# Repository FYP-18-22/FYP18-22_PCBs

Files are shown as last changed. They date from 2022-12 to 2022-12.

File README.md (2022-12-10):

This repository holds all our electrical and electronics designs.

Contains files for a main PCB and an actuation PCB.

The main PCB uses an STM32F103CC controller and provides for interfacing with various sensors. It also interacts with our actuation PCB by accepting the zero-crossing detection signal from the actuation PCB and sends back actuation commands to it.

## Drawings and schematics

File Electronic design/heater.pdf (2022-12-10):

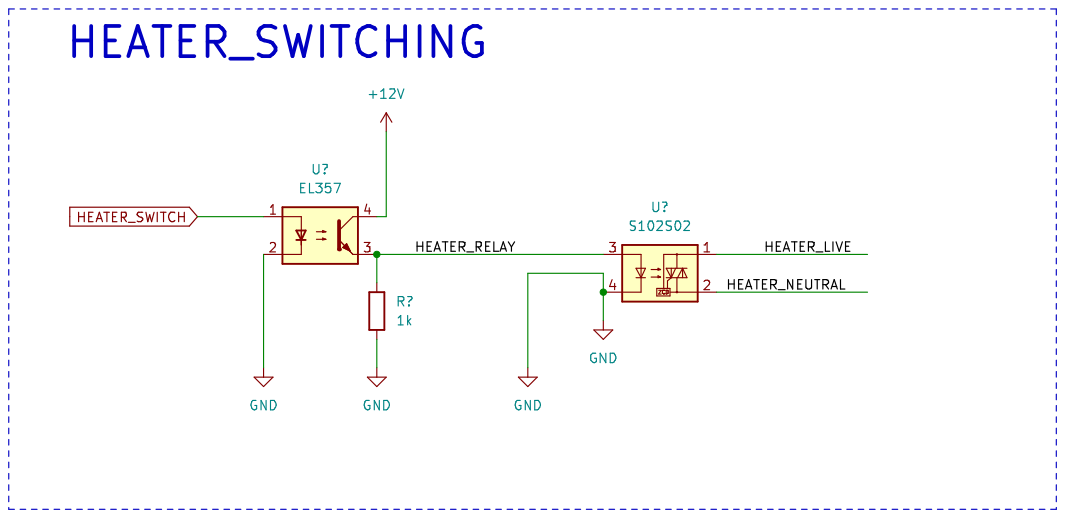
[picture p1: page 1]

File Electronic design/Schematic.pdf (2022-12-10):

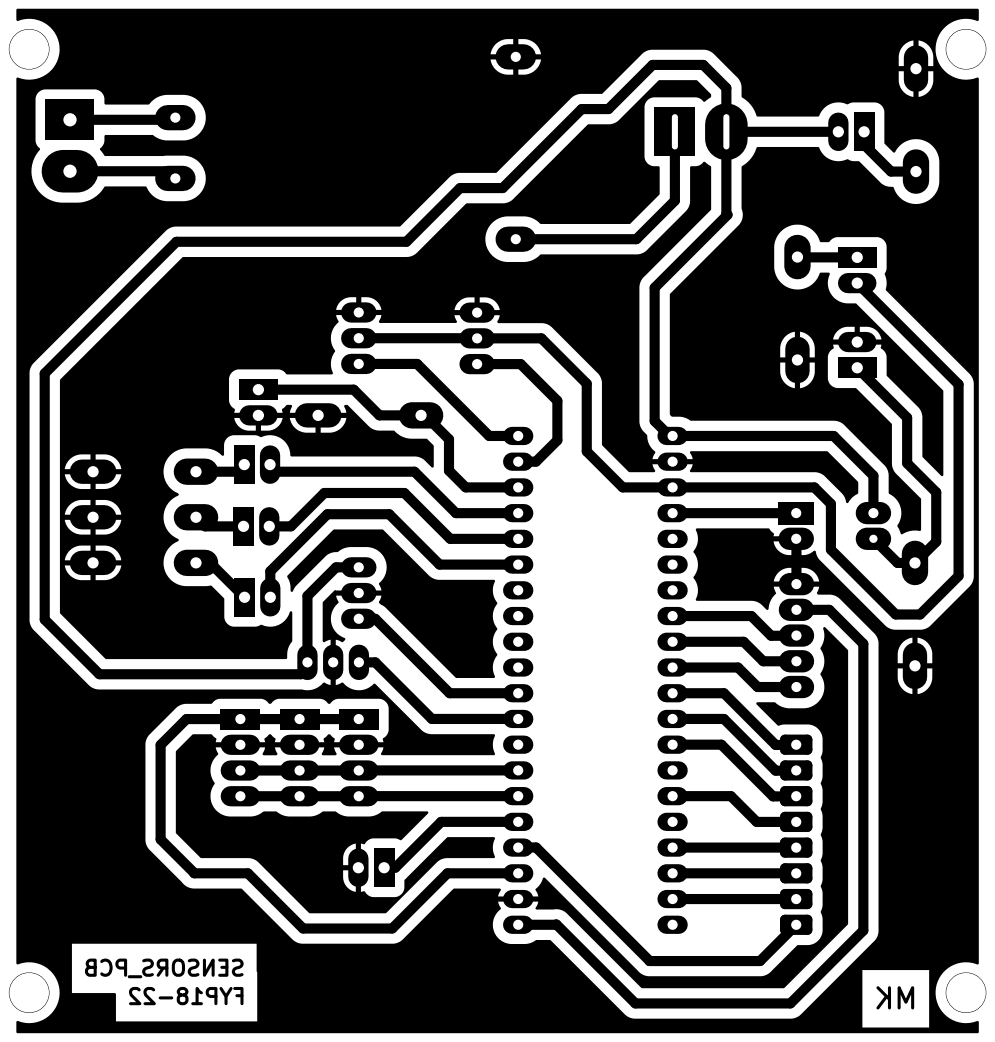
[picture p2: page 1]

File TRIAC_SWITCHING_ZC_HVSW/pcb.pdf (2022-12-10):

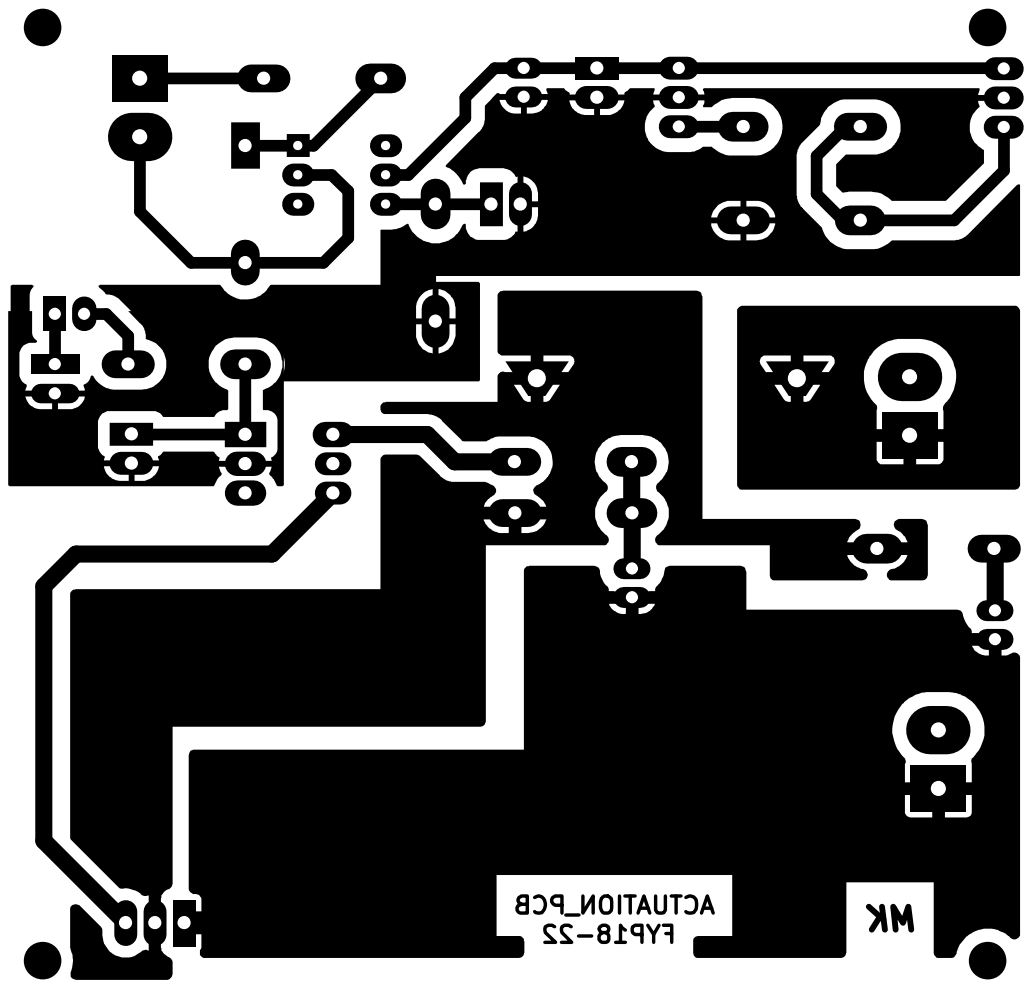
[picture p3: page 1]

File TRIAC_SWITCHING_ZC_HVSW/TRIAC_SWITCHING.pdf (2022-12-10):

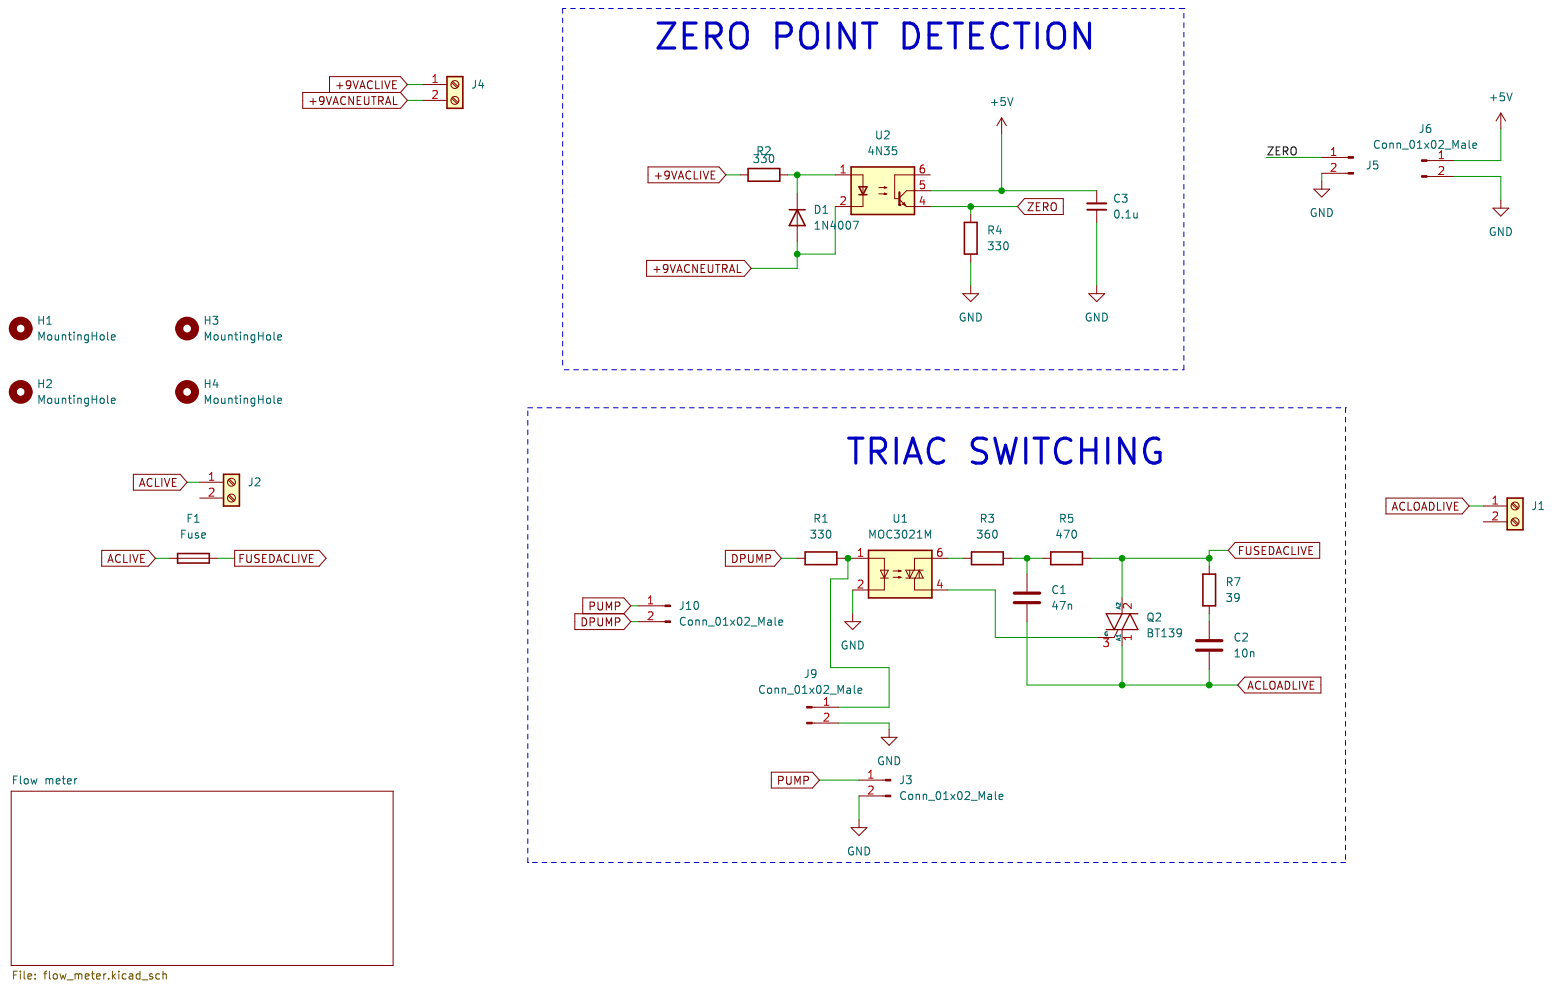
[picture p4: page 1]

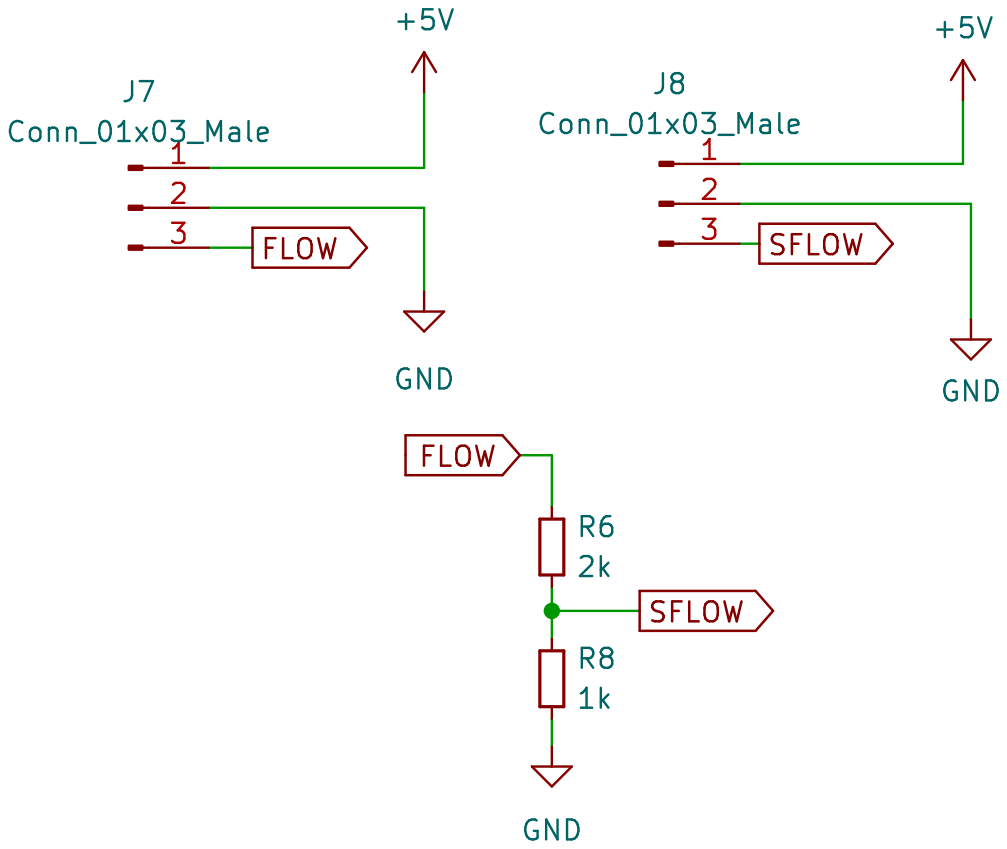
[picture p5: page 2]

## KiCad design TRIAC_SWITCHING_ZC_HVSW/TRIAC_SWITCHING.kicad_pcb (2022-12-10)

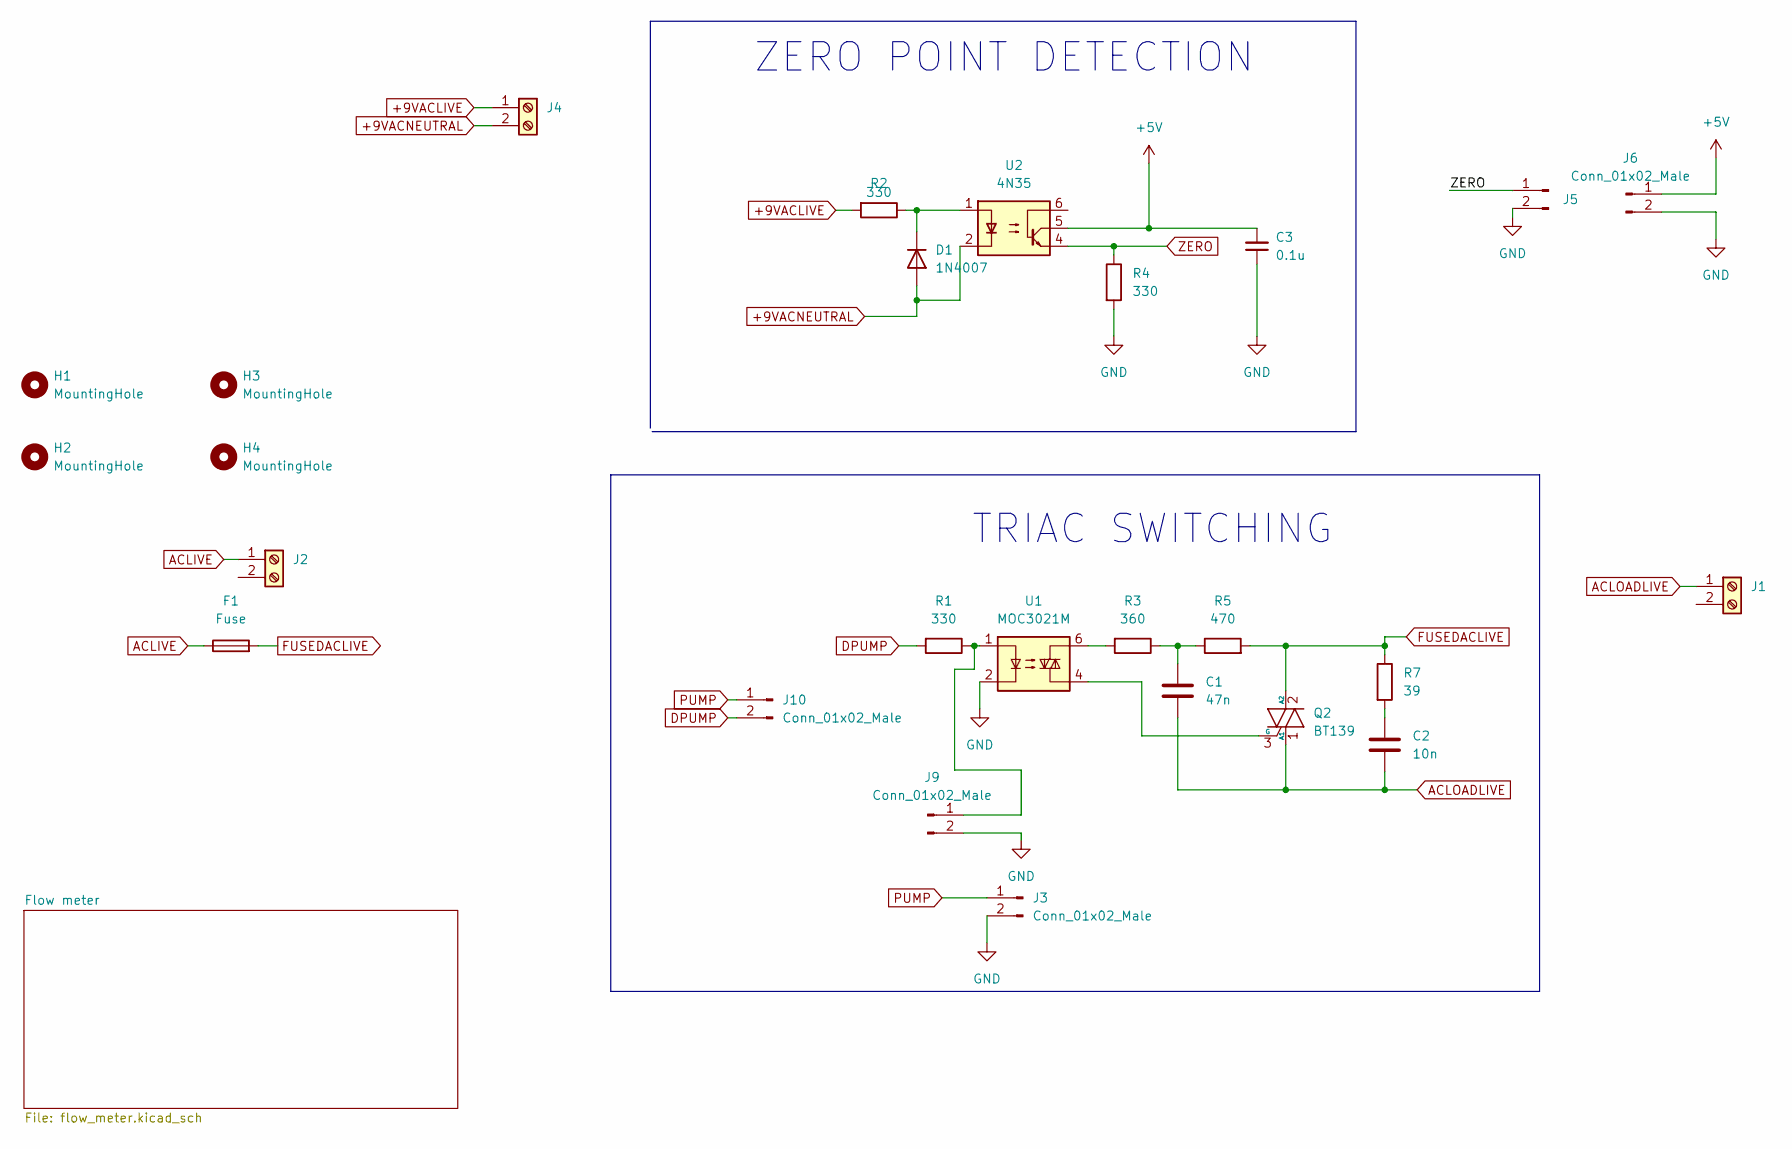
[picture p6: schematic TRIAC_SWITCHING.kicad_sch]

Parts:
C1: 47n; CP_Radial_D5.0mm_P2.50mm
C2: 10n; CP_Radial_D5.0mm_P2.50mm
C3: 0.1u; CP_Radial_D5.0mm_P2.50mm
D1: 1N4007; D_DO-41_SOD81_P10.16mm_Horizontal
F1: Fuse; Fuseholder_Cylinder-5x20mm_Stelvio-Kontek_PTF78_Horizontal_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
H1, H2, H3, H4: MountingHole; MountingHole_3.2mm_M3
J1, J2, J4: Screw_Terminal_01x02; TerminalBlock_Phoenix_MKDS-1,5-2-5.08_1x02_P5.08mm_Horizont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
J3, J5, J6, J9, J10: Conn_01x02_Male; PinHeader_1x02_P2.54mm_Vertical
Q2: BT139; TO-220-3_Vertical
R1, R2, R4: 330; R_Axial_DIN0207_L6.3mm_D2.5mm_P10.16mm_Horizontal
R3: 360; R_Axial_DIN0207_L6.3mm_D2.5mm_P10.16mm_Horizontal
R5: 470; R_Axial_DIN0207_L6.3mm_D2.5mm_P10.16mm_Horizontal
R7: 39; R_Axial_DIN0207_L6.3mm_D2.5mm_P10.16mm_Horizontal
U1: MOC3021M; DIP-6_W7.62mm
U2: 4N35; DIP-6_W7.62mm

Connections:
+5V: C3.2, J6.1, U2.5; also elsewhere on the board
+9VACLIVE: J4.1, R2.2
+9VACNEUTRAL: D1.2 (A), J4.2, U2.2
ACLIVE: F1.1, J2.1
ACLOADLIVE: C1.2, C2.2, J1.1, Q2.1 (A1)
DPUMP: J10.2, R1.2
FUSEDACLIVE: F1.2, Q2.2 (A2), R5.2, R7.1
GND: C3.1, J3.2, J5.2, J6.2, J9.2, R4.2, U1.2; also elsewhere on the board
unnamed: C1.1, R3.1, R5.1
unnamed: C2.1, R7.2
unnamed: D1.1 (K), R2.1, U2.1
unnamed: J9.1, R1.1, U1.1
unnamed: Q2.3 (G), U1.4
unnamed: R3.2, U1.6
PUMP: J3.1, J10.1
ZERO: J5.1, R4.1, U2.4

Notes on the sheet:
TRIAC SWITCHING
ZERO POINT DETECTION

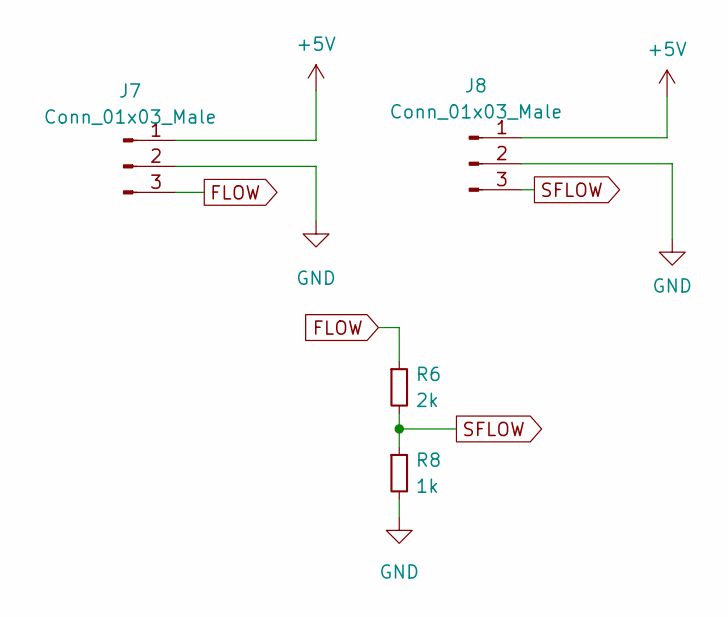
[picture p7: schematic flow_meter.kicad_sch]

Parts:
J7, J8: Conn_01x03_Male; PinHeader_1x03_P2.54mm_Vertical
R6: 2k; R_Axial_DIN0207_L6.3mm_D2.5mm_P10.16mm_Horizontal
R8: 1k; R_Axial_DIN0207_L6.3mm_D2.5mm_P10.16mm_Horizontal

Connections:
+5V: J7.1, J8.1; also elsewhere on the board
FLOW: J7.3, R6.1
GND: J7.2, J8.2, R8.2; also elsewhere on the board
SFLOW: J8.3, R6.2, R8.1

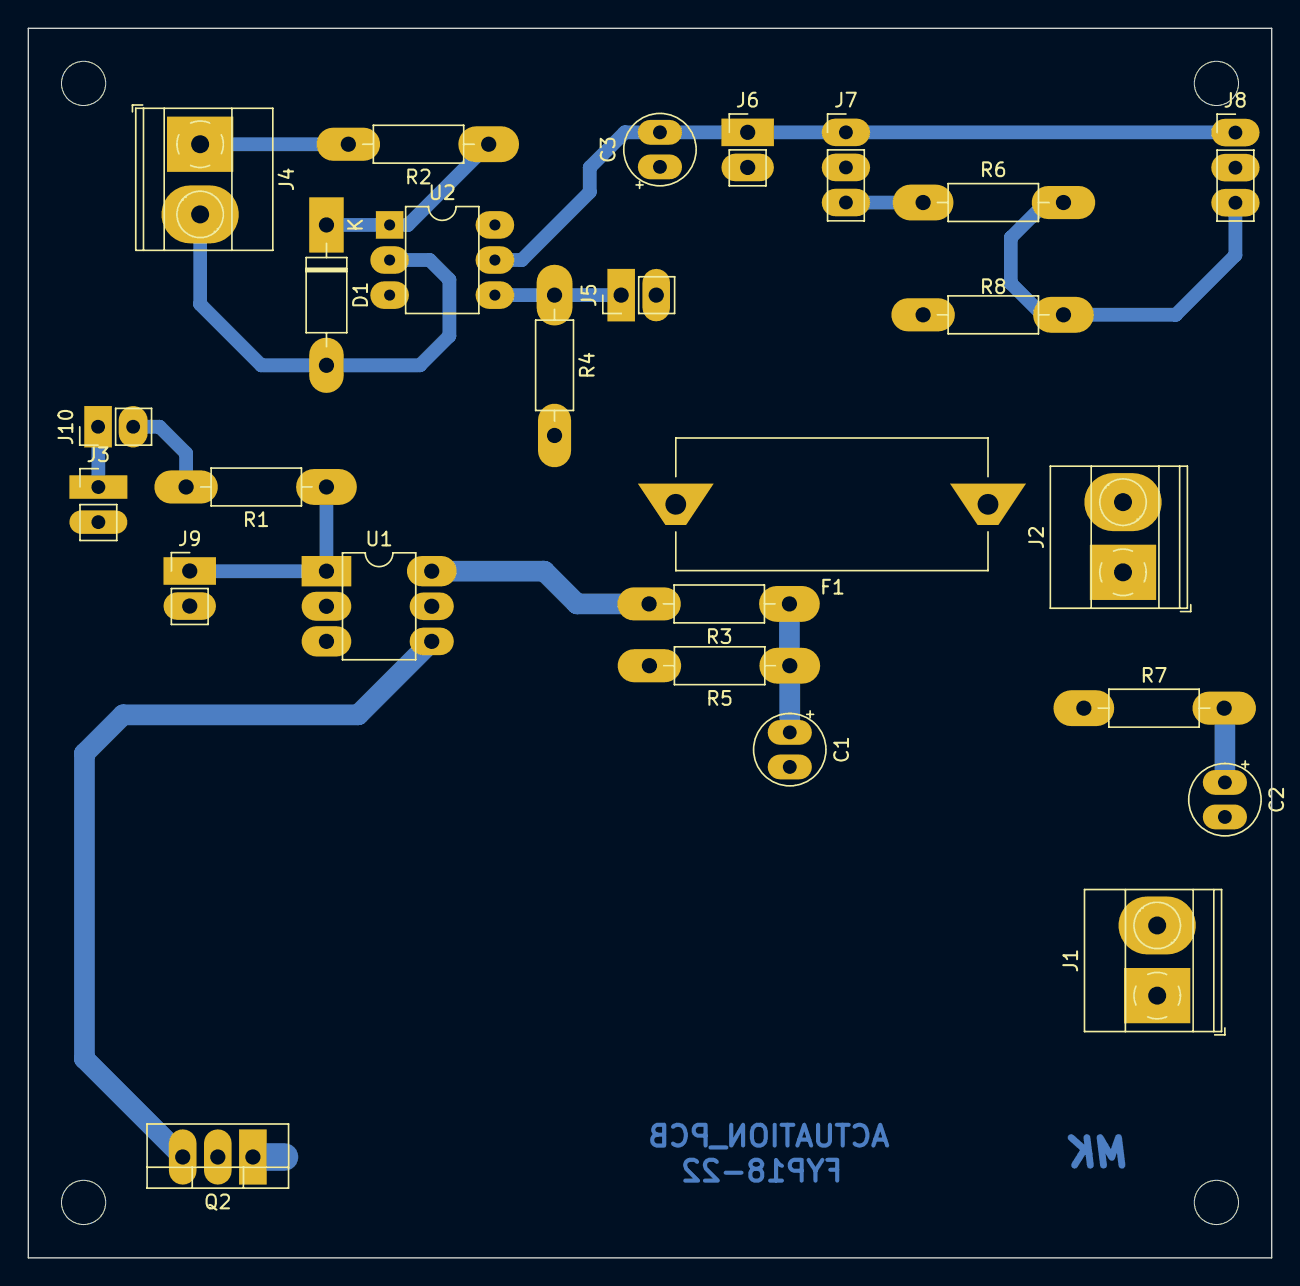
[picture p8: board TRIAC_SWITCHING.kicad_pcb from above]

Board: 2 copper layers, 90.0 x 89.0 mm, 30 parts (0 on the bottom side), 18 nets.

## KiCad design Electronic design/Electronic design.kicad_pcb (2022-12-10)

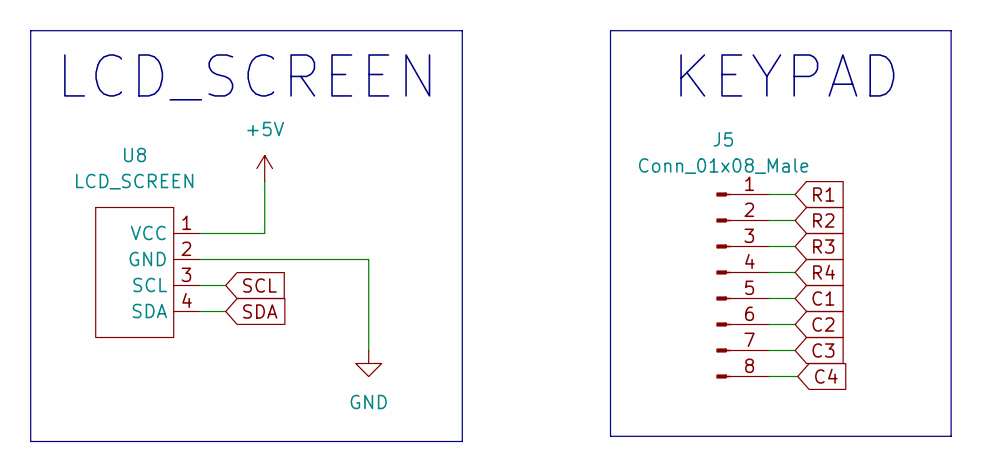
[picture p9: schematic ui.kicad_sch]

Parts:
J5: Conn_01x08_Male; PinHeader_1x08_P2.54mm_Vertical
U8: LCD_SCREEN; PinHeader_1x04_P2.54mm_Vertical

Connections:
+5V: U8.1 (VCC); also elsewhere on the board
C1: J5.5; also elsewhere on the board
C2: J5.6; also elsewhere on the board
C3: J5.7; also elsewhere on the board
C4: J5.8; also elsewhere on the board
GND: U8.2 (GND); also elsewhere on the board
R1: J5.1; also elsewhere on the board
R2: J5.2; also elsewhere on the board
R3: J5.3; also elsewhere on the board
R4: J5.4; also elsewhere on the board
SCL: U8.3 (SCL); also elsewhere on the board
SDA: U8.4 (SDA); also elsewhere on the board

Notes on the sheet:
KEYPAD
LCD_SCREEN

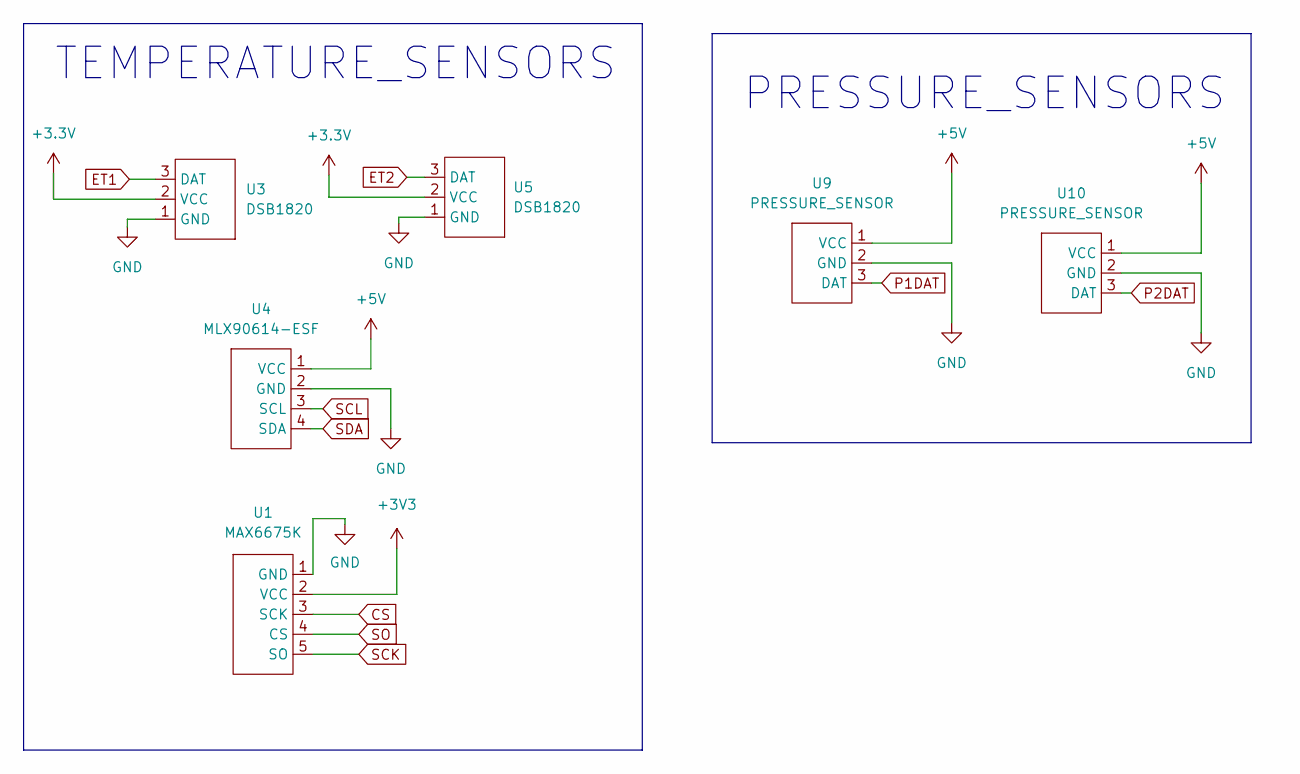
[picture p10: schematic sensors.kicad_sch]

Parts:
U1: MAX6675K; PinHeader_1x05_P2.54mm_Vertical
U3, U5: DSB1820; PinHeader_1x03_P2.54mm_Vertical
U4: MLX90614-ESF; PinHeader_1x04_P2.54mm_Vertical
U9, U10: PRESSURE_SENSOR; PinHeader_1x03_P2.54mm_Vertical

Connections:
+5V: U4.1 (VCC), U9.1 (VCC), U10.1 (VCC); also elsewhere on the board
CS: U1.3 (SCK); also elsewhere on the board
ET1: U3.3 (DAT); also elsewhere on the board
ET2: U5.3 (DAT); also elsewhere on the board
GND: U1.1 (GND), U3.1 (GND), U4.2 (GND), U5.1 (GND), U9.2 (GND), U10.2 (GND); also elsewhere on the board
P1DAT: U9.3 (DAT); also elsewhere on the board
P2DAT: U10.3 (DAT); also elsewhere on the board
SCK: U1.5 (SO); also elsewhere on the board
SCL: U4.3 (SCL); also elsewhere on the board
SDA: U4.4 (SDA); also elsewhere on the board
SO: U1.4 (CS); also elsewhere on the board

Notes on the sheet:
PRESSURE_SENSORS
TEMPERATURE_SENSORS

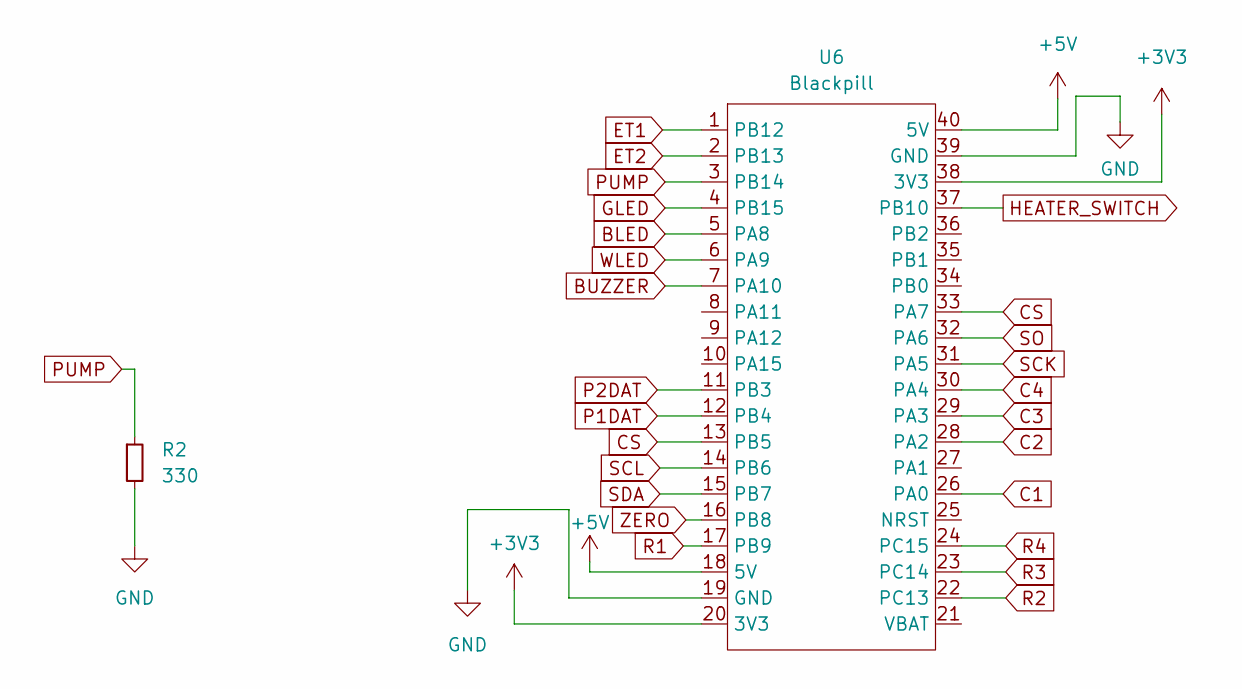
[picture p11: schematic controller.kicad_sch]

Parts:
R2: 330; R_Axial_DIN0207_L6.3mm_D2.5mm_P10.16mm_Horizontal
U6: Blackpill

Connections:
+5V: U6.18 (5V), U6.40 (5V); also elsewhere on the board
BLED: U6.5 (PA8); also elsewhere on the board
BUZZER: U6.7 (PA10)
C1: U6.26 (PA0); also elsewhere on the board
C2: U6.28 (PA2); also elsewhere on the board
C3: U6.29 (PA3); also elsewhere on the board
C4: U6.30 (PA4); also elsewhere on the board
CS: U6.13 (PB5), U6.33 (PA7); also elsewhere on the board
ET1: U6.1 (PB12); also elsewhere on the board
ET2: U6.2 (PB13); also elsewhere on the board
GLED: U6.4 (PB15); also elsewhere on the board
GND: R2.2, U6.19 (GND), U6.39 (GND); also elsewhere on the board
HEATER_SWITCH: U6.37 (PB10); also elsewhere on the board
P1DAT: U6.12 (PB4); also elsewhere on the board
P2DAT: U6.11 (PB3); also elsewhere on the board
PUMP: R2.1, U6.3 (PB14); also elsewhere on the board
R1: U6.17 (PB9); also elsewhere on the board
R2: U6.22 (PC13); also elsewhere on the board
R3: U6.23 (PC14); also elsewhere on the board
R4: U6.24 (PC15); also elsewhere on the board
SCK: U6.31 (PA5); also elsewhere on the board
SCL: U6.14 (PB6); also elsewhere on the board
SDA: U6.15 (PB7); also elsewhere on the board
SO: U6.32 (PA6); also elsewhere on the board
WLED: U6.6 (PA9); also elsewhere on the board
ZERO: U6.16 (PB8); also elsewhere on the board

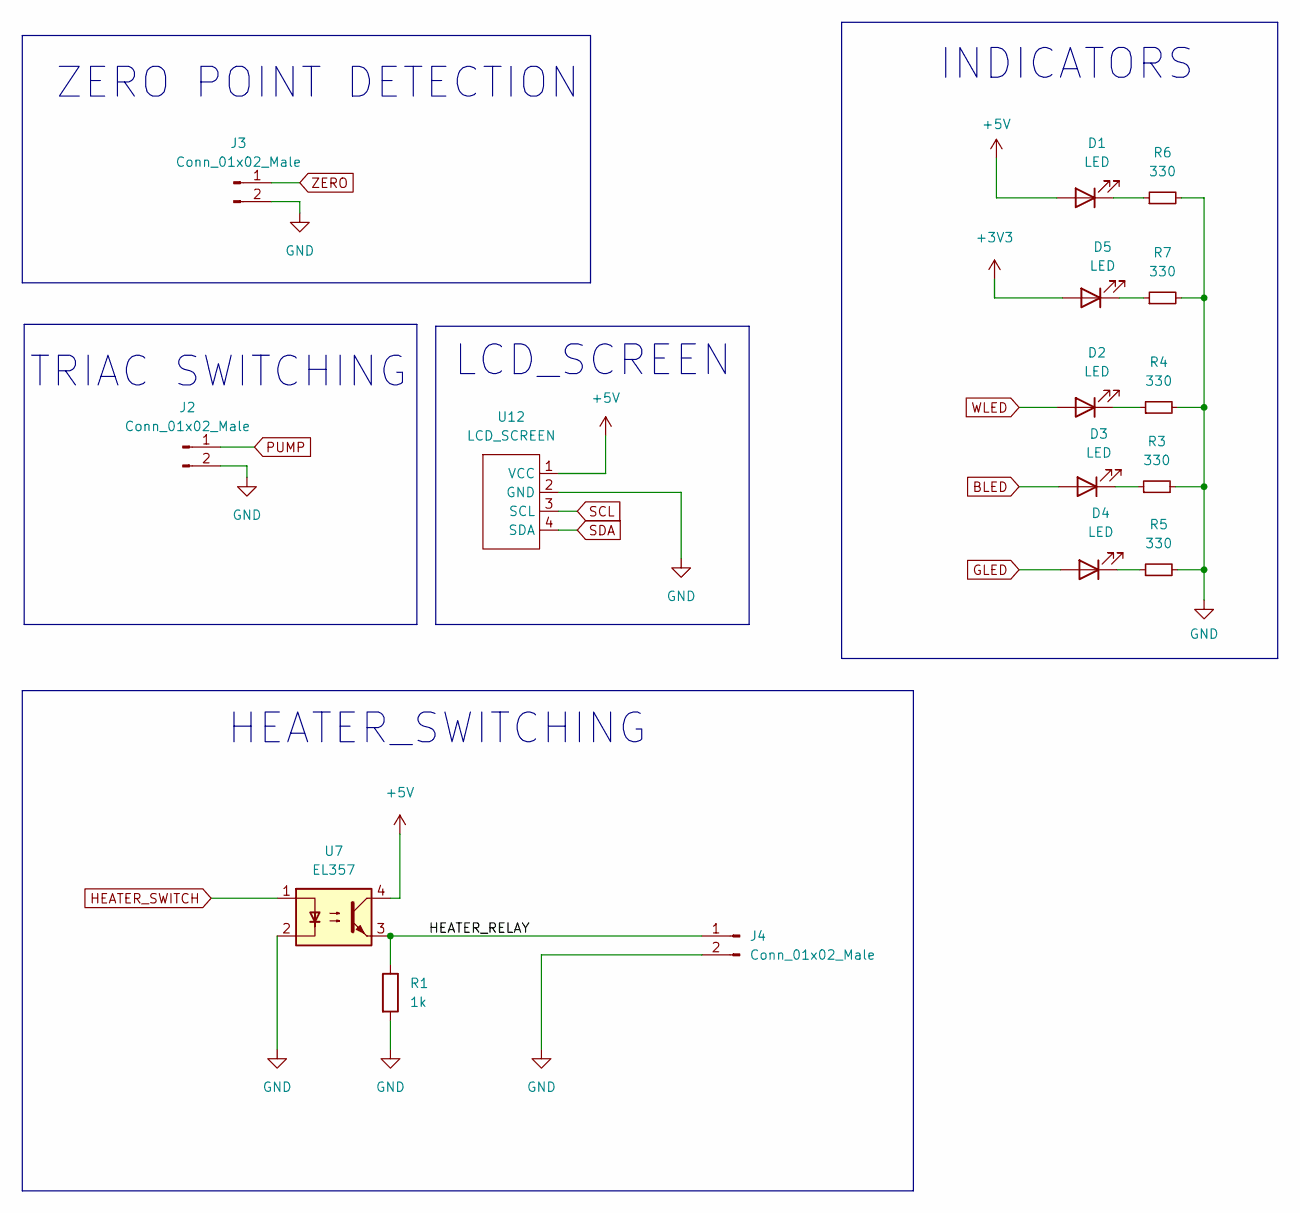
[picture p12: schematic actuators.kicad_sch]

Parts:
D1, D2, D3, D4, D5: LED; PinHeader_1x02_P2.54mm_Vertical
J2, J3, J4: Conn_01x02_Male; PinHeader_1x02_P2.54mm_Vertical
R1: 1k; R_Axial_DIN0207_L6.3mm_D2.5mm_P10.16mm_Horizontal
R3, R4, R5, R6, R7: 330; R_Axial_DIN0207_L6.3mm_D2.5mm_P10.16mm_Horizontal
U7: EL357; DIP-4_W7.62mm; LCSC Part Number C6649
U12: LCD_SCREEN; PinHeader_1x04_P2.54mm_Vertical

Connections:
+5V: D1.2 (A), U7.4, U12.1 (VCC); also elsewhere on the board
/Actuators/HEATER_RELAY: J4.1, R1.1, U7.3
BLED: D3.2 (A); also elsewhere on the board
GLED: D4.2 (A); also elsewhere on the board
GND: J2.2, J3.2, J4.2, R1.2, R3.2, R4.2, R5.2, R6.2, R7.2, U7.2, U12.2 (GND); also elsewhere on the board
HEATER_SWITCH: U7.1; also elsewhere on the board
unnamed: D1.1 (K), R6.1
unnamed: D2.1 (K), R4.1
unnamed: D3.1 (K), R3.1
unnamed: D4.1 (K), R5.1
unnamed: D5.1 (K), R7.1
PUMP: J2.1; also elsewhere on the board
SCL: U12.3 (SCL); also elsewhere on the board
SDA: U12.4 (SDA); also elsewhere on the board
WLED: D2.2 (A); also elsewhere on the board
ZERO: J3.1; also elsewhere on the board

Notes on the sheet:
HEATER_SWITCHING
ZERO POINT DETECTION
INDICATORS
LCD_SCREEN
TRIAC SWITCHING

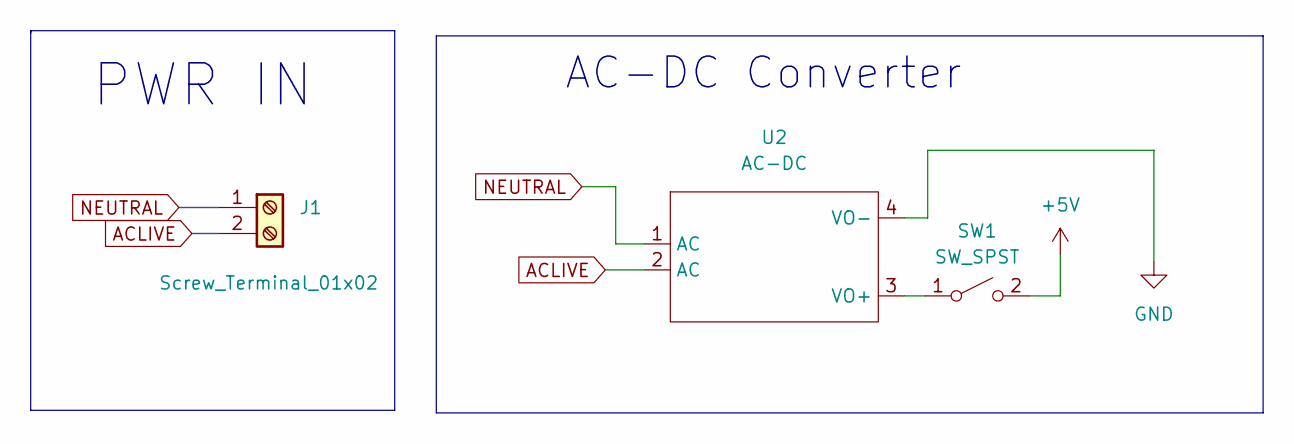
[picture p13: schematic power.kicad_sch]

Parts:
J1: Screw_Terminal_01x02; TerminalBlock_Phoenix_MKDS-1,5-2-5.08_1x02_P5.08mm_Horizont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
SW1: SW_SPST; KCD1 switch
U2: AC-DC; AC_DC

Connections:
+5V: SW1.2 (B); also elsewhere on the board
ACLIVE: J1.2, U2.2 (AC)
GND: U2.4 (VO-); also elsewhere on the board
NEUTRAL: J1.1, U2.1 (AC)
unnamed: SW1.1 (A), U2.3 (VO+)

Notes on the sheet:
PWR IN
AC-DC Converter

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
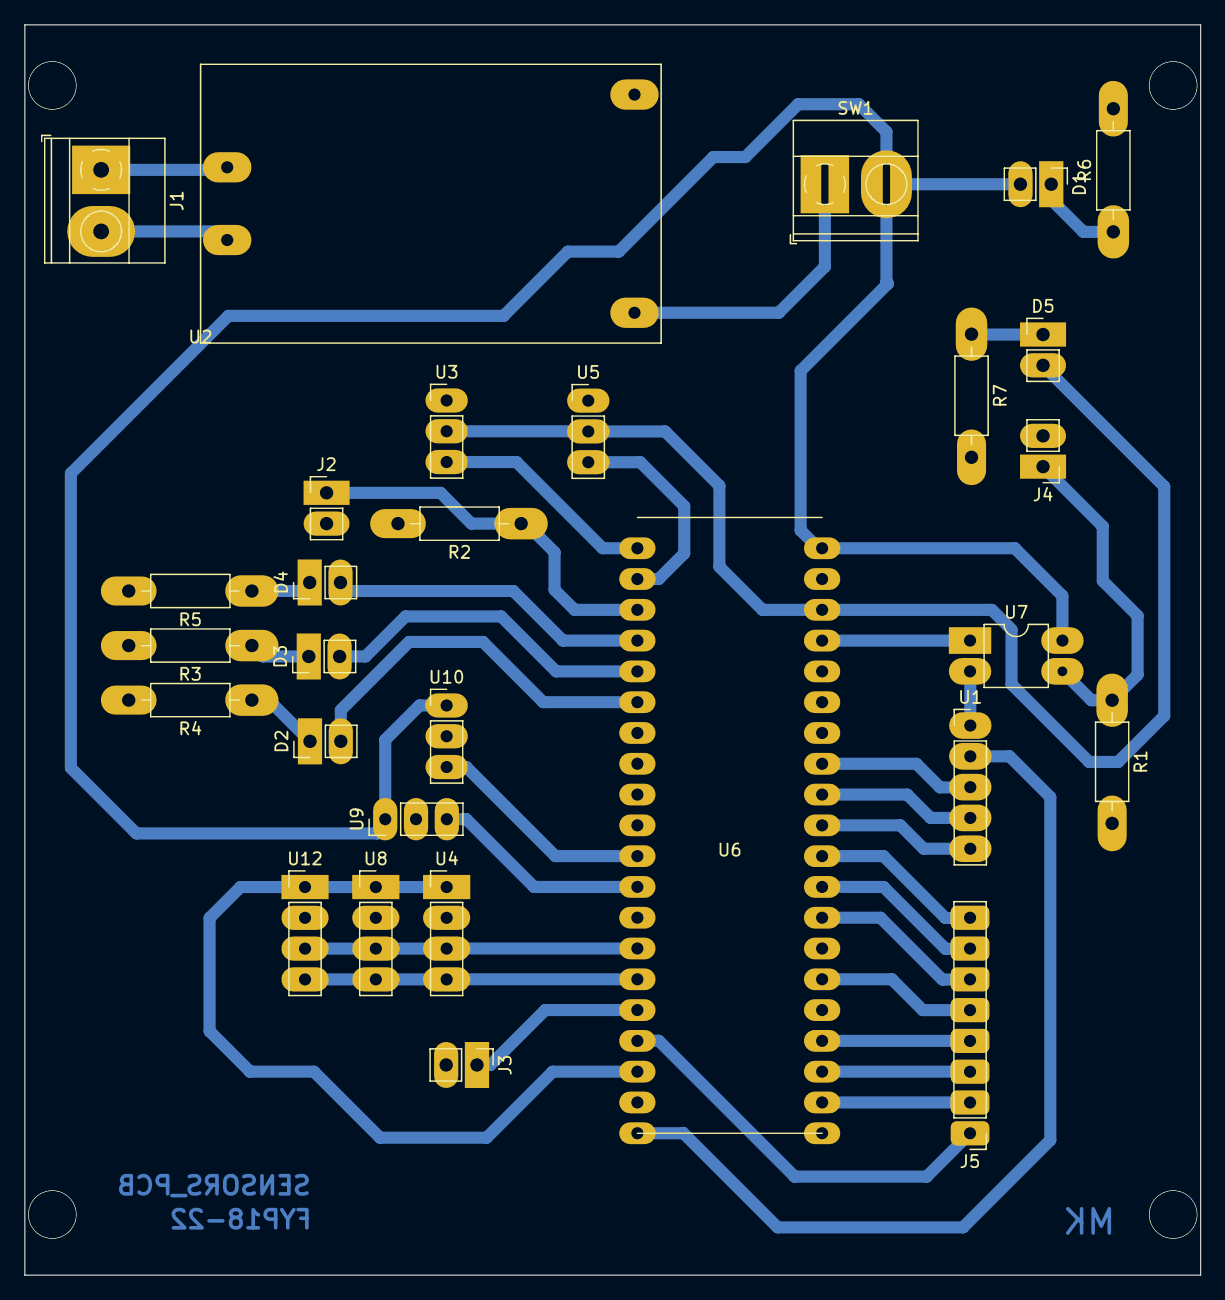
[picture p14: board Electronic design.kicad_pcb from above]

Board: 2 copper layers, 97.0 x 103.1 mm, 29 parts (0 on the bottom side), 35 nets.

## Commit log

2022-12-10 Electronics for the presentstion
    [Electronic design.kicad_pcb, Electronic design.kicad_sch, TRIAC_SWITCHING.kicad_pcb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]
2023-01-04 Last changes
    [power.kicad_sch]
